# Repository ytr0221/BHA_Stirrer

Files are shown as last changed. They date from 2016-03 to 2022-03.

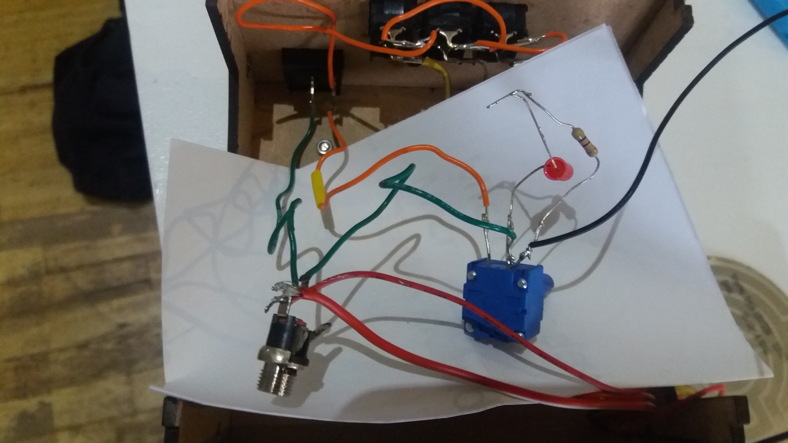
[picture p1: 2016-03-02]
Pictures/20160302_162144.jpg

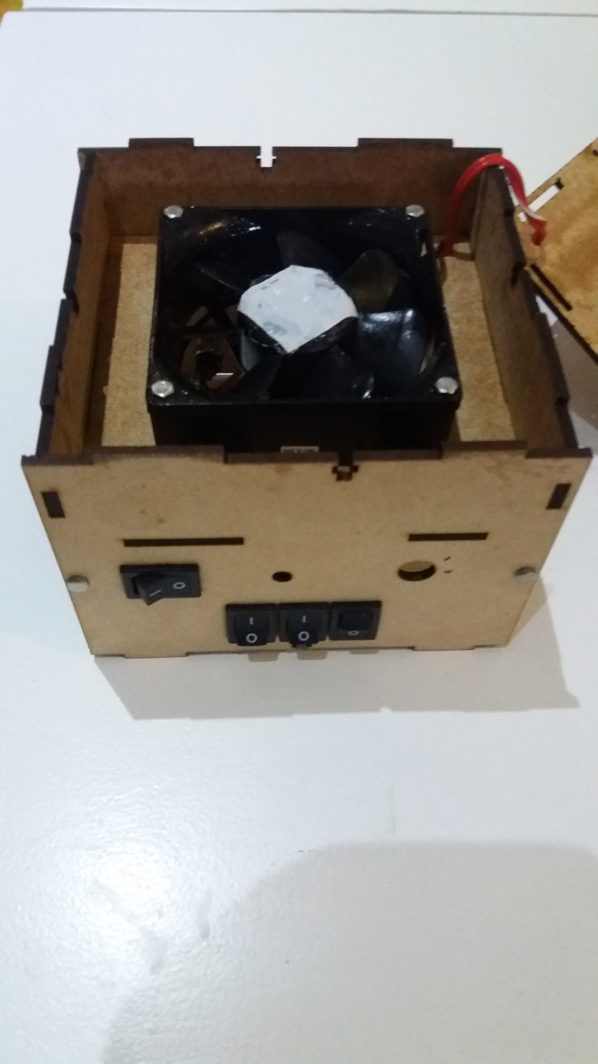
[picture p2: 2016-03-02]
Pictures/20160302_162333.jpg

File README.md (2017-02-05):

#NOTE  
Please add a 100 ohm resistor to the if the stirring thing gets thrown inside.   

#BHA Stirrer
This repo contains the designs and source files of a **DIY Magnetic Stirrer**. Such a device is used to stir liquids continiously for a long period of time. The optional heating pad keeps the liquid warm, it is not design for boiling or cooking.

The electronics of this device demonstrate parallel and serial wiring schemes. Instead of using 3 switches to set the power of the heating pad, you could also go for a potential meter.

##Navigation the repo

 	BHA_Stirrer/						main repo
 	|-- Pictures/						Photo documentation
 	BoM.md								Bill of Materials
 	Magnetic-Stirrer-Cut-Sheet.svg		Laser cut sheet
 	Magentic-Stirrer-Fritzing.fzz		Wiring documentation
 	Magnetic-Stirrer-Sketchup.skp		Sketchup 3D desi

##Releases

The BioHack Academy 3 release contains the following:

* 2015 BHA1 Design
* 2015 BHA2 Design
* 2016 BHA3 Design

## To Do

* Temperature control via feedback loop

Please maket more suggestions by posting in the Issues section of this GitHub Repo.

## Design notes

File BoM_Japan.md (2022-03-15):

## 部品リスト

このプロジェクトにはArduinoなどは要りません。 3mmアクリル板とM3サイズのナットを用意してください。
### Must have

|No|個数|品|購入できる場所|価格|参考|
| ---: | ---: | :--- | :--- | ---: | :--- |
|1|1|80 mm ファン(PC用)|[Tsukumo](http://shop.tsukumo.co.jp/goods/4937925913084/), [Monotaro](https://www.monotaro.com/g/00866020/)|¥514||
|2|2|ネオジム磁石|ダイソー|¥100||
|3|1|ポテンショメータ 100Ω 2W|[RS Online](https://jp.rs-online.com/mobile/p/potentiometers/5225254/)|¥898||
|4|4|ロッカースイッチ|[RS Online](https://jp.rs-online.com/mobile/p/rocker-switches/7182247/), [Monotaro](https://www.monotaro.com/g/00163769/)|¥96||
|5|1|DCジャック|[Akizuki](http://akizukidenshi.com/catalog/g/gC-06342/)|¥60||
|6|1|7.5 W power supply|[Amazon](https://www.amazon.co.jp/AC%E3%82%A2%E3%83%80%E3%83%97%E3%82%BF%E3%83%BC-%E5%A4%A7%E6%89%8B%E3%83%A1%E3%83%BC%E3%82%AB%E3%83%BCOEM%E7%A4%BE%E8%A3%BD%E5%93%81-%E3%82%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)|¥800||
|7|1|LED(赤)|[RS Online](http://jp.rs-online.com/web/p/visible-leds/3208667/)|¥45.7||
|8|1|470Ω 抵抗|[RS Online](http://jp.rs-online.com/web/p/through-hole-fixed-resistors/4911291/)|¥74.30||
|9|1|回転子|[Monotaro](https://www.monotaro.com/g/01145071/?displayId=24)|¥129-199||
|10|4|ゴム足|[Amazon](http://amzn.asia/bm0HBuH), [RS Online](http://jp.rs-online.com/web/p/fixed-height-mounts-feet/4171796/)|¥399||
|11|1|フィルムヒーター|[Monotaro(ペルチェ素子)](https://www.monotaro.com/g/00363679/?t.q=%83y%83%8B%83%60%83F%91f%8Eq)|¥2091||
|12|3|68Ω 5V 抵抗|[RS Online](http://jp.rs-online.com/web/p/through-hole-fixed-resistors/7629456/)|¥43.96||
|13|1|アロンアルファ|そこらへん [Amazon (普通)](http://amzn.asia/2qJ4oKK) [Amazon (速攻多用途タイプ)](http://amzn.asia/0jpU0Qh)|¥230 or ¥349||

*Estimate total:* around ¥5500

**Alternatives**

* You could use all kind of motors, for example from a hard drive.
* Take a USB coffee mug heater apart for the heating foil or use a cheap power resistor to save money

**TODO**
* List parts from same vendors

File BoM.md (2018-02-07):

## Bill of Materials

For this device you do not need an Arduino or equivalent microprocessor. Do make sure you have enough 3mm material to cut the design from and a bunch of M3 10mm bolts and nuts for the assembly.

### Must have

|No|Amount|Description|Supplier NL|Cost|
| ---: | ---: | :--- | :--- | ---: |
|1|1|80 mm Fan|[Farnell](http://nl.farnell.com/bisonic/sp802512l-03/fan-80x25mm-12vdc/dp/1832326), [EOO](http://www.eoo-bv.nl/index.php?_a=viewProd&productId=13244) |3.25|
|2|2|Permanent Magnets|[Supermagnete](http://www.supermagnete.nl/blokmagneten-neodymium-middelgroot/blokmagneet-10mm-x-10mm-x-5mm-neodymium-n42-vernikkeld_Q-10-10-05-N)|0.65|
|3|1|Potentiometer 100Ω 2W|[Farnell](http://nl.farnell.com/bourns/93r1a-r22-a05l/potentiometer-linear-100-ohm-10/dp/2321801), [Mouser](http://nl.mouser.com/ProductDetail/Bourns/3540S-1-151L/?qs=y%252bjD4UO5DKWx%252bnbasP7iSA%3d%3d), [RS Online](http://nl.rs-online.com/web/p/potentiometers/5225254/)|6.34|
|4|4|Power switch|[Farnell](http://nl.farnell.com/webapp/wcs/stores/servlet/ProductDisplay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), [iPrototype](https://iprototype.nl/products/components/buttons-switches/rocker-switch-large)|2.84|
|5|1|DC power jack|[Farnell](http://nl.farnell.com/multicomp/jr1819-rohs-psg01769/socket-low-voltage-2-1mm-chassis/dp/1216726), [EOO](http://www.eoo-bv.nl/index.php?_a=viewProd&productId=14342)|0.85|
|6|1|7.5W power supply|[iPrototype](https://iprototype.nl/products/accessoires/power/adapter), [EOO](http://www.eoo-bv.nl/index.php?_a=viewProd&productId=11642)|13.95|
|7|1|Red LED|[Farnell](http://nl.farnell.com/webapp/wcs/stores/servlet/ProductDisplay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), [EOO](http://www.eoo-bv.nl/index.php?_a=viewProd&productId=5942), [iPrototype](https://iprototype.nl/products/components/led-lcd/rood#)|0.06|
|8|1|470Ω resistor|[Farnell](http://nl.farnell.com/webapp/wcs/stores/servlet/ProductDisplay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), [iPrototype](https://iprototype.nl/products/components/resistors/470R), [EOO](http://www.eoo-bv.nl/index.php?_a=viewProd&productId=14841)|0.04|
|9|1|Magnetic Stirring Rod|[Hinmeijer](http://www.hinmeijer.nl/product/121939/Magneetroerstaafjes_ellipsvormig.aspx)|3.06|
|10|4|Rubber Feet|[Conrad](https://www.conrad.nl/nl/toolcraft-elastische-buffer-zelfklevend-pd2104sw-x-h-10-mm-x-4-mm-zwart-1-stuks-401489.html)|0.08|
|11|1|Heating Foil, 5V|[Sparkfun](https://www.sparkfun.com/products/11288), [Floris.cc](https://www.floris.cc/shop/en/general-components/514-heating-pad-5x10cm.html?search_query=warm&results=4), [Conrad](https://www.conrad.nl/nl/thermo-verwarmingsfolie-zelfklevend-12-vdc-12-vac-22-w-veiligheidstype-ipx4-90-mm-1216623.html)|4.50|
|12|3|68Ω 5W Power resistors|[Farnell](http://nl.farnell.com/webapp/wcs/stores/servlet/ProductDisplay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)|1.29|
|13|1|Superglue|[SuperMagnete](https://www.supermagnete.nl/eng/workshop-magnets/uhu-max-repair-adhesive-for-magnets-waterproof-without-solvents_WS-ADH-01)|8.08|

*Estimate total:* EUR 44.99

**Alternatives**

* You could use all kind of motors, for example from a hard drive.
* Take a USB coffee mug heater apart for the heating foil or use a cheap power resistor to save money

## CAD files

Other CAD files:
Magnetic-Stirrer-Sketchup.skp

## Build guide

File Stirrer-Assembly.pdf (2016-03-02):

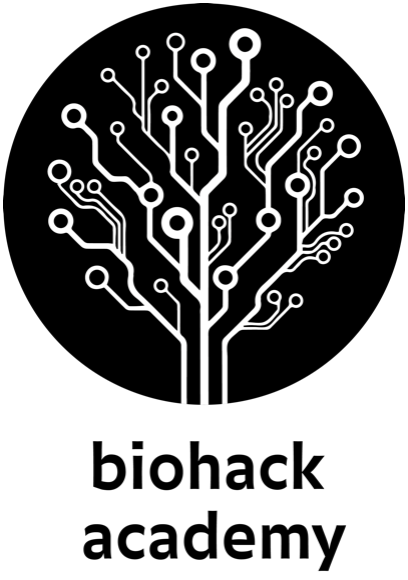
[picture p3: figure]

# Stirrer Assembly Guide

## Assembly the box and position of the magnets

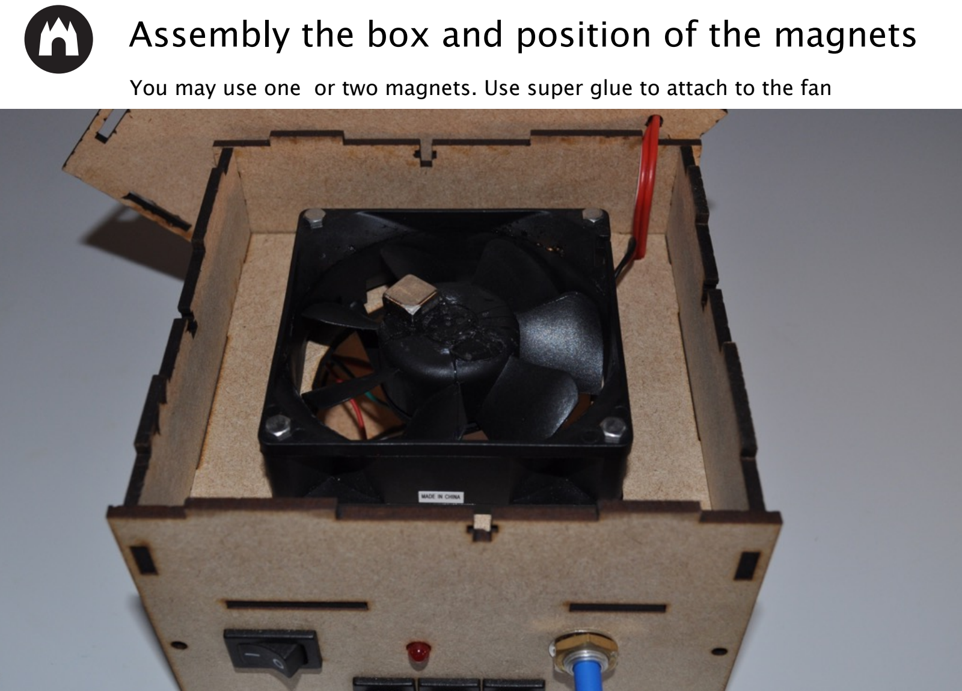
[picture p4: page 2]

You may use one or two magnets. Use super glue to attach to the fan

# Fan and LED circuit

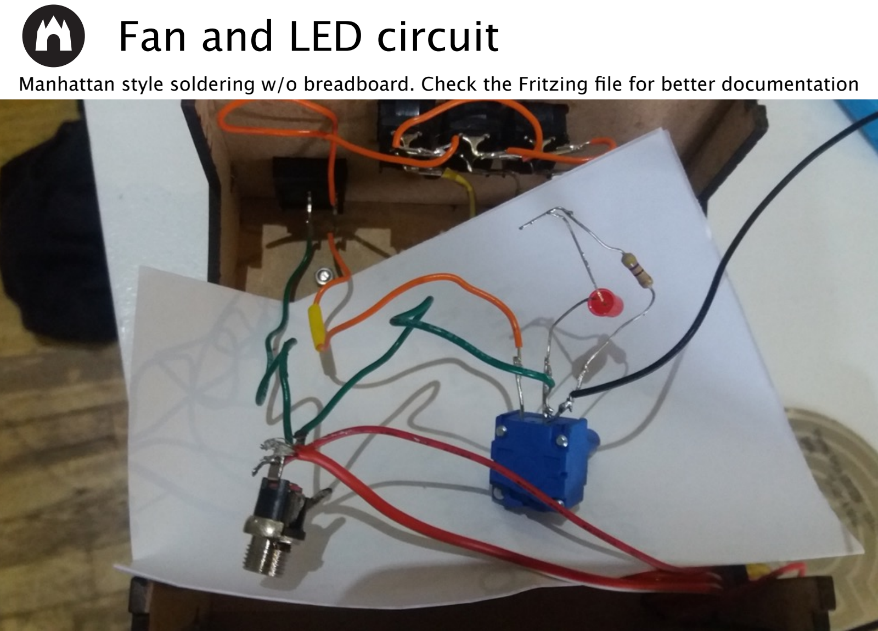
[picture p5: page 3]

Manhattan style soldering w/o breadboard. Check the Fritzing file for better documentation

# Heating pad wiring

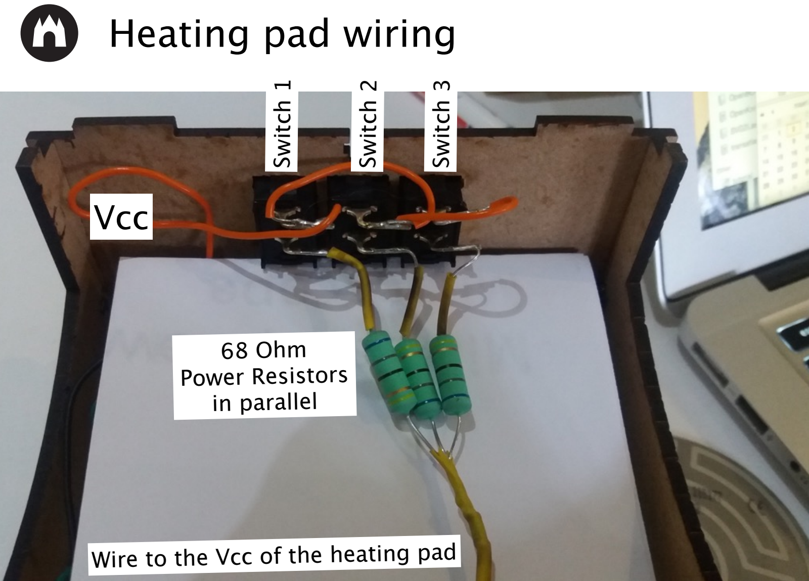
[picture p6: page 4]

# Vcc

## Switch 1

## Switch 2

## Switch 3

### 68 Ohm Power Resistors

### in parallel

### Wire to the Vcc of the heating pad

# Attach the bottom panel

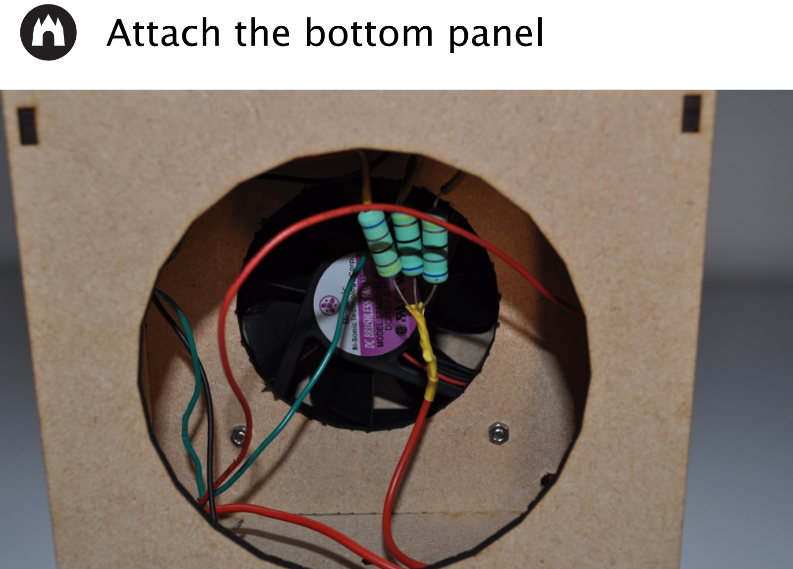
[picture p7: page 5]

# Put the lid on and mount the heating

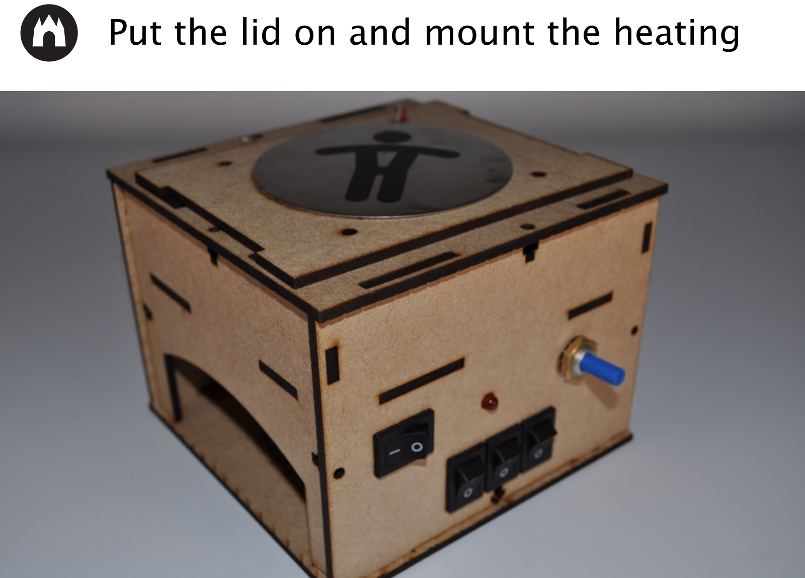
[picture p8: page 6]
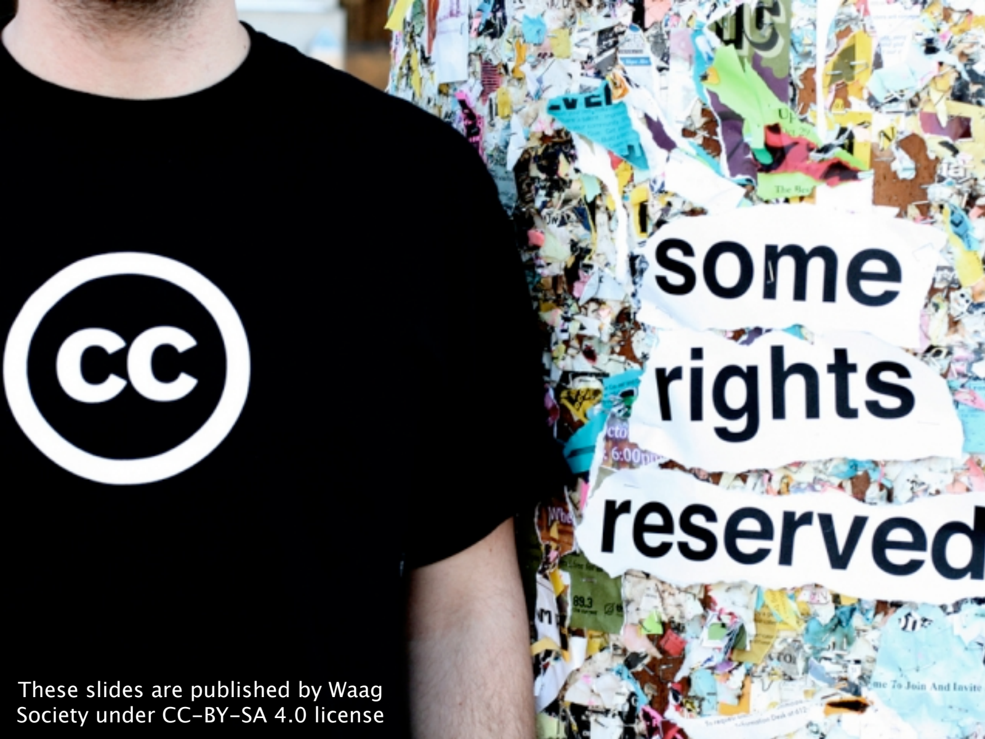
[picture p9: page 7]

These slides are published by Waag Society under CC-BY-SA 4.0 license

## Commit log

2015-07-20 Old version
    [Magnetic-Stirrer-Fritzing.fzz, Magnetic-Stirrer-Sketchup.skp]
2015-09-07 Magnetic Stirrer Push
    Adding extra files given to me by Michele
    [Magnetic-Stitrrer-Sketchup.skp]
2015-09-09 BoM Update
2016-02-16 update design
    [Magnetic-Stirrer-Fritzing.fzz, Magnetic-Stirrer-Sketchup.skp, Magnetic-Stirrer-Sketchup~.skp]
2016-03-02 pictures + assembly guide
2016-11-11 clean up old versions
    [Magnetic-Stirrer-Fritzing.fzz, Magnetic-Stirrer-Sketchup.skp]
2016-11-25 update BHA4
    [Magnetic-Stirrer-Sketchup.skp]
2016-12-16 BHA4 update
    [Magnetic-Stirrer-Fritzing.fzz, Magnetic-Stirrer-Sketchup.skp, Magnetic-Stirrer-Sketchup~.skp]
2017-01-12 BoM Japan
2022-03-15 changed stirrer rod to cheaper one
